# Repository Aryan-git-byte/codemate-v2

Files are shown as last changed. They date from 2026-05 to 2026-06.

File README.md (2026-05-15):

# Overview:
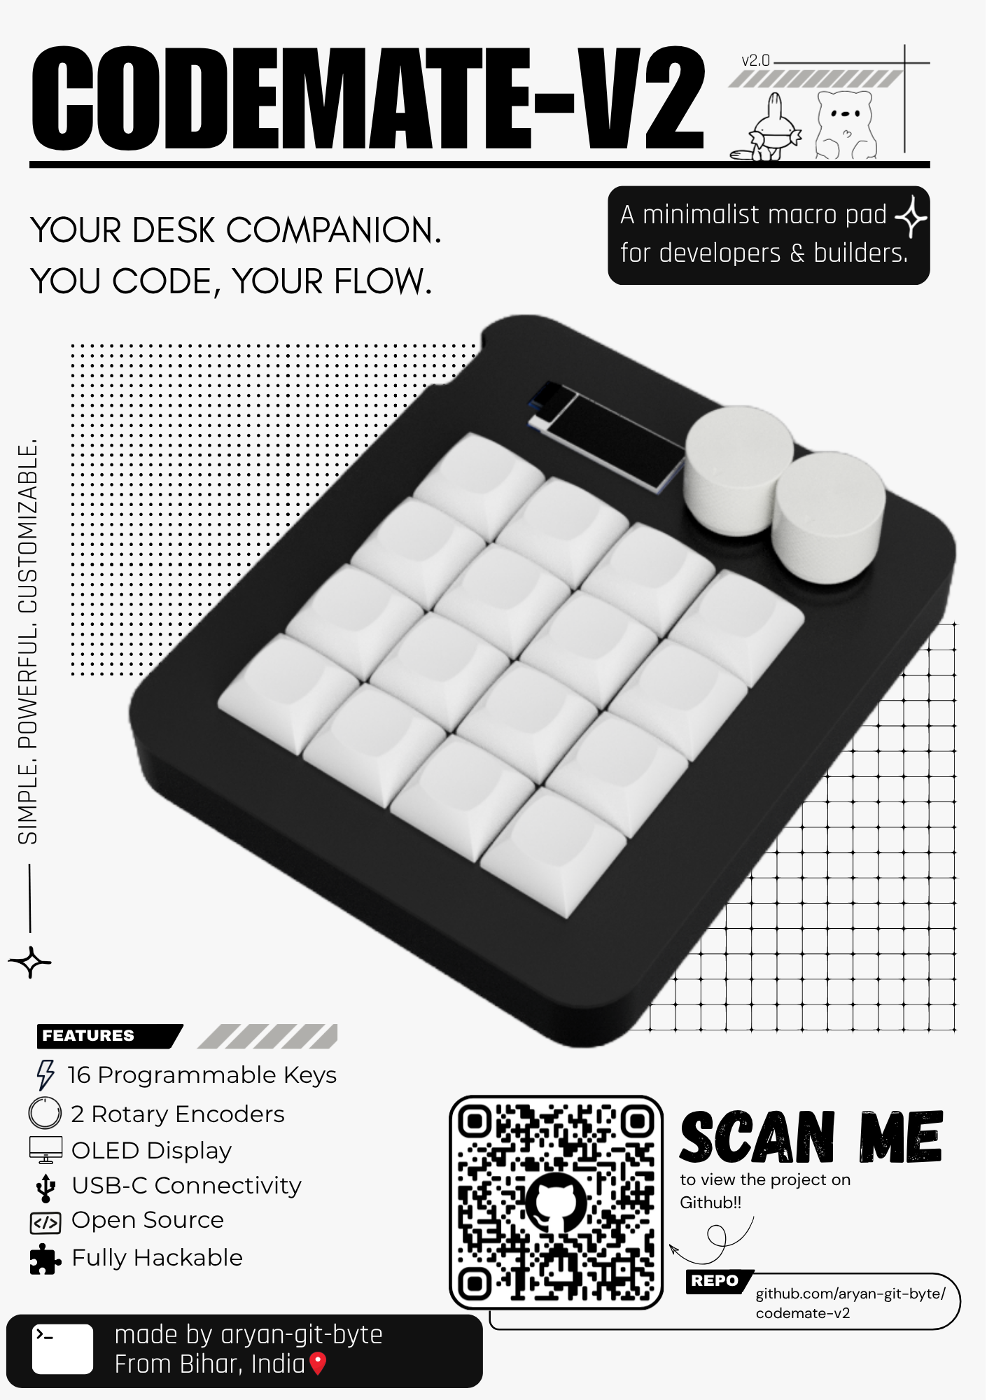
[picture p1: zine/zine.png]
zine

# What is this??
Yo, this is a 4x4 custom macropad that you can use for making ur life ezz, lol
it has 16 macros, 2 rotary encoders, RGB lights and an OLED display. and also it is a successor of my previous macropad [Codemate](https://github.com/aryan-git-byte/codemate).
# Use case:
whether you are a programmer, 3d modeller, editor or whatever u can easily use this macropad with just a little bit tweak in its firmware.
# Schematic Overview:
this is the schematic of the project, which u can see here:
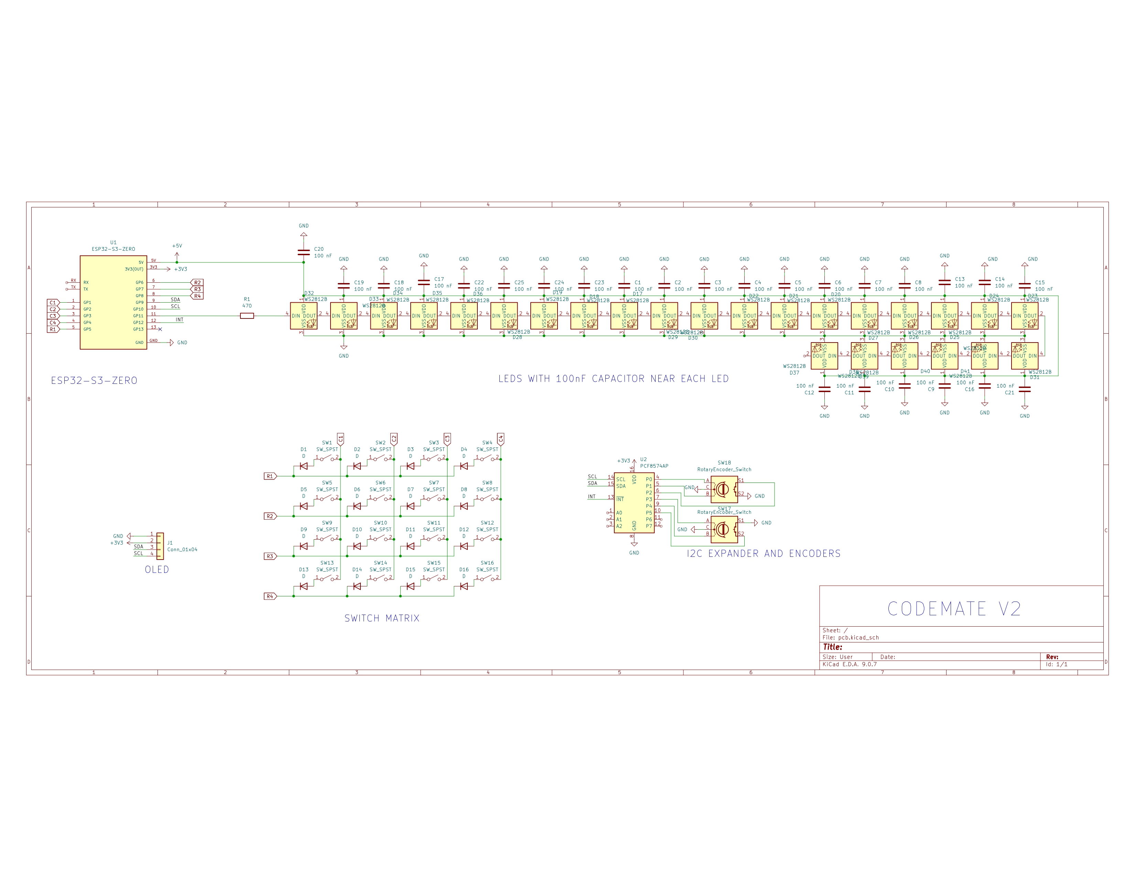
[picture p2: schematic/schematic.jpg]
schematic

you can see the MCU, the key matrix, the LEDs, encoders, everything in this schematic.
# why i made it??
cuz i believe that having a macropad can ezz my workflow and also give make it faster and more efficient.
# PCB overview:
for this i am using a 2 layer pcb board:
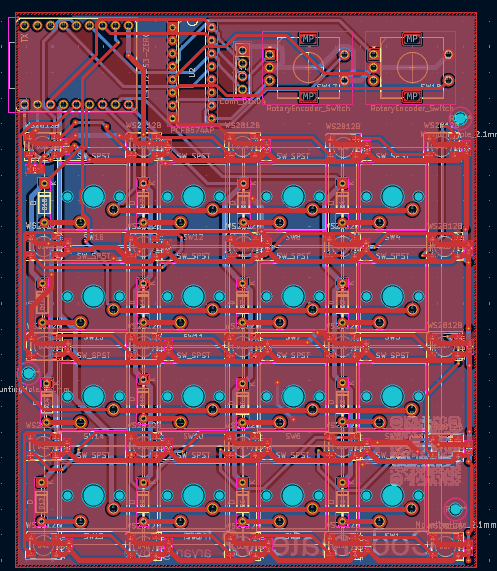
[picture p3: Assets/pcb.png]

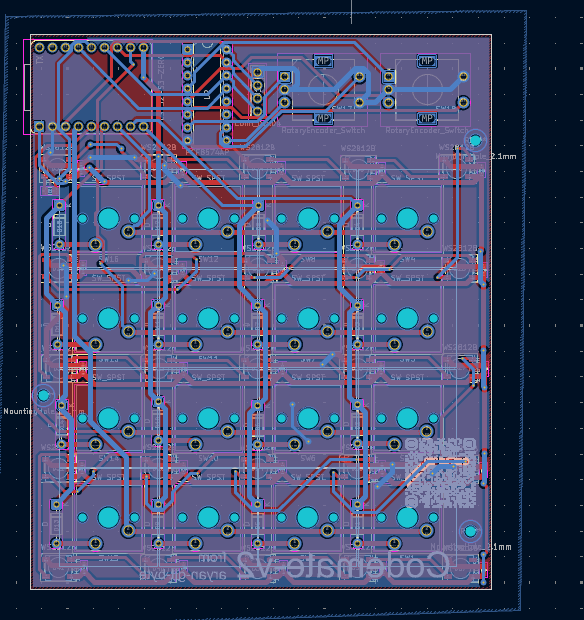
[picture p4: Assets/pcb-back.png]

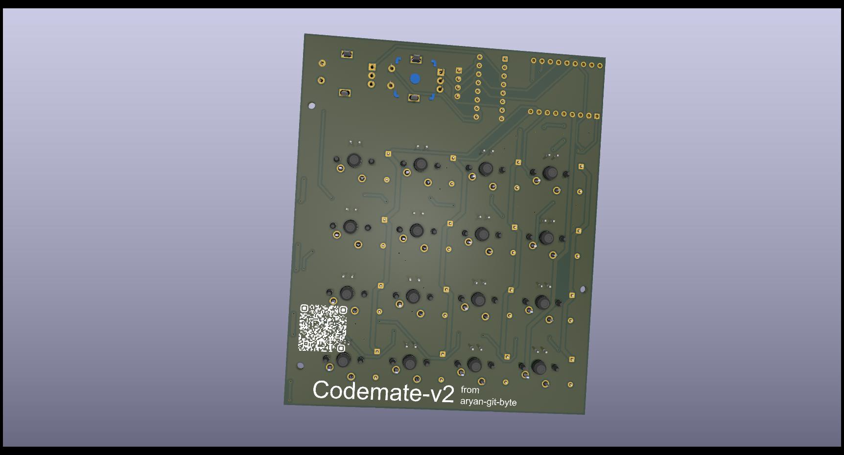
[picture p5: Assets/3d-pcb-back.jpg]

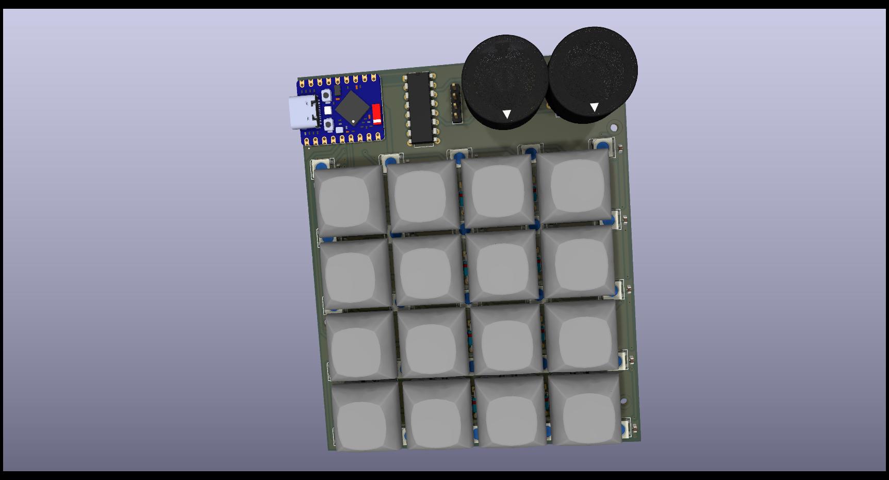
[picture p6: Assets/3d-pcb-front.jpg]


# How to Assemble
1. get the pcb ordered and solder all the components to it carefully
2. get these things 3d printed:
    1. [top-plate](3D-models/printable/TopPanel.stl) - 1x
    2. [main-body](3D-models/printable/Main-Body.stl) - 1x
    3. [keycaps](<3D-models/printable/DSA 1u.step>) - 16x
    4. [encoders](3D-models/printable/EncoderKnob.step) - 2x
3. cover it with the top plate
4. drill a 2 mm hole near the red holes:
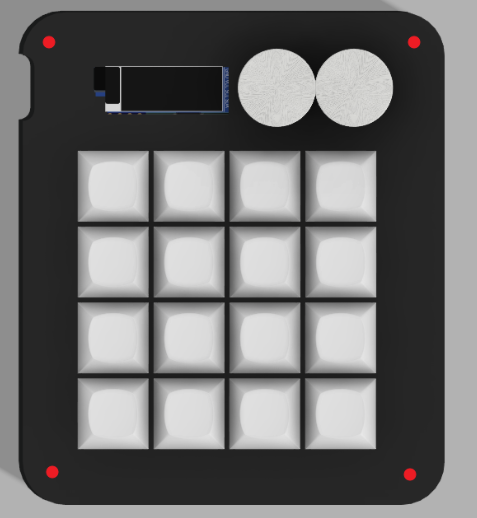
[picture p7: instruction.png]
instruction

5. insert 4 m3 inserts in these holes on the main body.
6. Now, put the soldered pcb with all the components inside the main-body
7. put the top panel , and put m3 screws. 
8. now put the keycaps and the knob onto it.
9. enjoy <3
# Firmware:
written in Arduino framework for ESP32-S3 Zero using these libraries:
- [FastLED](https://github.com/FastLED/FastLED) — RGB control
- [Keypad](https://github.com/Chris--A/Keypad) — key matrix
- [Adafruit SSD1306](https://github.com/adafruit/Adafruit_SSD1306) — OLED
- [Adafruit PCF8574](https://github.com/adafruit/Adafruit-PCF8574) — IO expander for encoders
- USB HID (built into ESP32 Arduino core) — keyboard + media keys

### flashing steps:
1. opem [Arduino IDE](https://www.arduino-cc/en/software)
2. add ESP32 board support — paste this in Board Manager URL:
   `https://raw.githubusercontent.com/espressif/arduino-esp32/gh-pages/package_esp32_index.json`
3. install the libraries above from Library Manager
4. select board: `ESP32S3 Dev Module`
5. plug in USB into the devboard
6. upload `firmware/firmware.ino` from this repo
7. done
# BOM:
|item name | quantity | unit price | link | total price
|-|-|-|-|-
Esp32-s3 zero development board|1| 620 rs | [link](https://hubtronics.in/esp32-s3-zero-m?srsltid=AfmBOoq3kT32v8UczG0TNtBfSk1mz6VMTDCRHNpQfM2GaU1SiqyRmEIawpQ)| 620 rs 
Blue MX cherry switches ( pack of 10)| 2 | 350 rs | [link](https://meckeys.com/shop/accessories/keyboard-accessories/key-switches/cherry-mx2a-switch/)| 700 rs
Oled 0.91"|1|198 rs |[link](https://hubtronics.in/0.91inch-4pin-oled-display-module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)|198 rs 
PCF8574AP | 1 | 124 rs | [link](https://robu.in/product/pcf8574an-texas-instruments-pcf8574an-i-o-expander-8-bit-i2c-2-5-v-6-v-dip-16-pins/)|128 rs
EC11 rotary encoder|2|64 rs | [link](https://www.flyrobo.in/15mm-ec11-rotary-encoder-with-switch-digital-potentiometer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) | 128 rs 
WS2812B | 40 | 4.72 rs | [link](https://hubtronics.in/ws2812b-5050-led?srsltid=AfmBOopNwODVwO3OMV0OqoXZXVZTHtyzRN5Mug-3Q1g00d0sAzbv55LT4r4)| 188.80 rs
470 ohm 0805 resistor (pack of 20)| 1| 8 rs | [link](https://quartzcomponents.com/products/470ohm-470e-5-smd-resistor-0805-pack-of-20-pieces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)|8 rs
100 nF Capacitor 0603 (pack of 20)|2|11 rs | [link](https://quartzcomponents.com/products/kemet-100nf-50v-0603-smd-pack-x7r-multilayer-ceramic-capacitor-10-tolerence-pack-of-20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)| 22 rs
 Diode (1N4148)|25|3 rs |[link](https://quartzcomponents.com/products/1n4148-zener-diode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)|75 rs
hubtroncs shipping charge| 1 | 75 rs | | 75 rs 
Meckkeys shipping charge | 1 | 100 rs | | 100 rs
FlyRobo shipping | 1 | 59 rs | | 59 rs 

[ Note: the components from the quartz component and robu are budled with my other order of different project, otherwise if u are ordering it for yourself , it will be 100 rs each ]

Total: 2301 rs , (24 usd)

## PCB will be :   
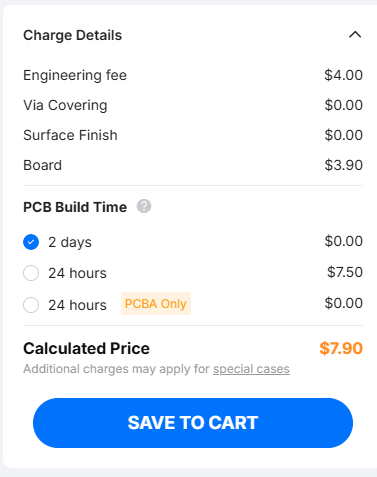
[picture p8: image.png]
jlcpcb
        

7 usd, shipping will be another 10 usd, but i m getting this shipped along with my different pcb.

# grand total : 31 usd

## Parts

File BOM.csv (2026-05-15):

item name | quantity | unit price | link | total price
Esp32-s3 zero development board | 1 | 620 rs | https://hubtronics.in/esp32-s3-zero-m | 620 rs
Blue MX cherry switches ( pack of 10) | 2 | 350 rs | https://meckeys.com/shop/accessories/keyboard-accessories/key-switches/cherry-mx2a-switch/ | 700 rs
Oled 0.91" | 1 | 198 rs | https://hubtronics.in/0.91inch-4pin-oled-display-module | 198 rs
PCF8574AP | 1 | 124 rs | https://robu.in/product/pcf8574an-texas-instruments-pcf8574an-i-o-expander-8-bit-i2c-2-5-v-6-v-dip-16-pins/ | 128 rs
EC11 rotary encoder | 2 | 64 rs | https://www.flyrobo.in/15mm-ec11-rotary-encoder-with-switch-digital-potentiometer?tracking=ads | 128 rs
WS2812B | 40 | 4.72 rs | https://hubtronics.in/ws2812b-5050-led | 188.80 rs
470 ohm 0805 resistor (pack of 20) | 1 | 8 rs | https://quartzcomponents.com/products/470ohm-470e-5-smd-resistor-0805-pack-of-20-pieces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 | 8 rs
100 nF Capacitor 0603 (pack of 20) | 2 | 11 rs | https://quartzcomponents.com/products/kemet-100nf-50v-0603-smd-pack-x7r-multilayer-ceramic-capacitor-10-tolerence-pack-of-20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 | 22 rs
Diode (1N4148) | 25 | 3 rs | https://quartzcomponents.com/products/1n4148-zener-diode?variant=42817413546218&country=IN&currency=INR | 75 rs
hubtroncs shipping charge | 1 | 75 rs |  | 75 rs
Meckkeys shipping charge | 1 | 100 rs |  | 100 rs
FlyRobo shipping | 1 | 59 rs |  | 59 rs
PCB | 1 | 7 usd |  | 7 usd
PCB shipping | 1 | 10 usd |  | 10 usd
grand total | 1 | 31 usd |  | 31 usd

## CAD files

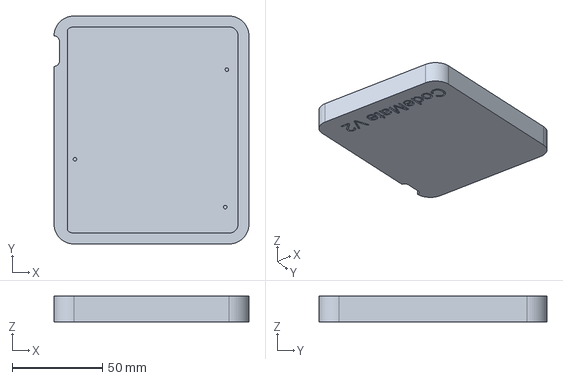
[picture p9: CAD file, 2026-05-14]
3D-models/printable/Main-Body.step
107.8 x 126.0 x 14.3 mm

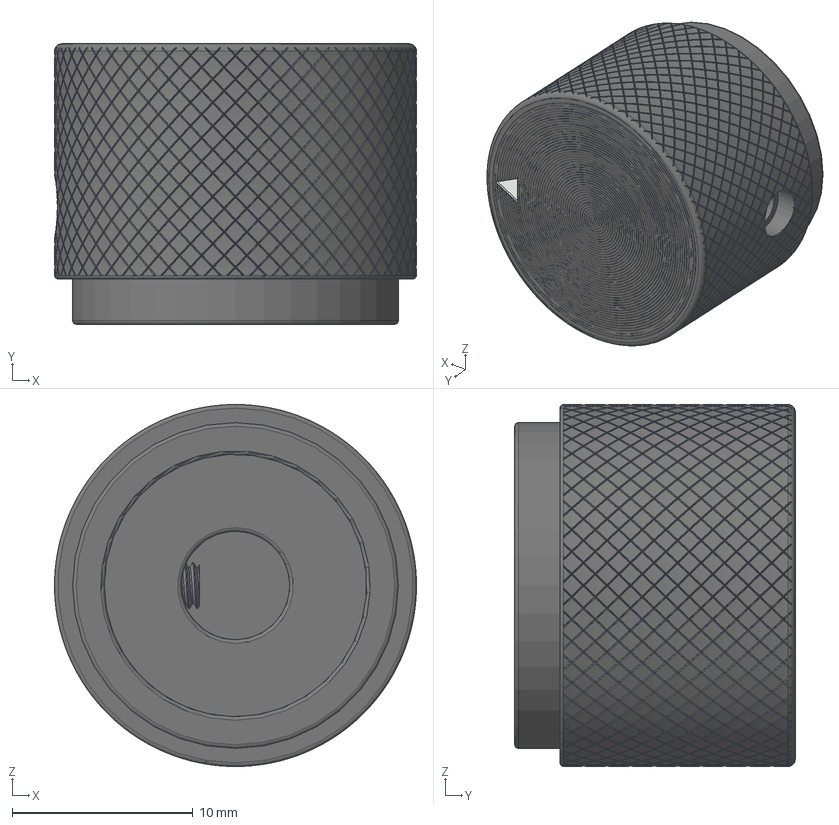
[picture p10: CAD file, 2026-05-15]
3D-models/printable/EncoderKnob.step
20.0 x 15.5 x 20.0 mm

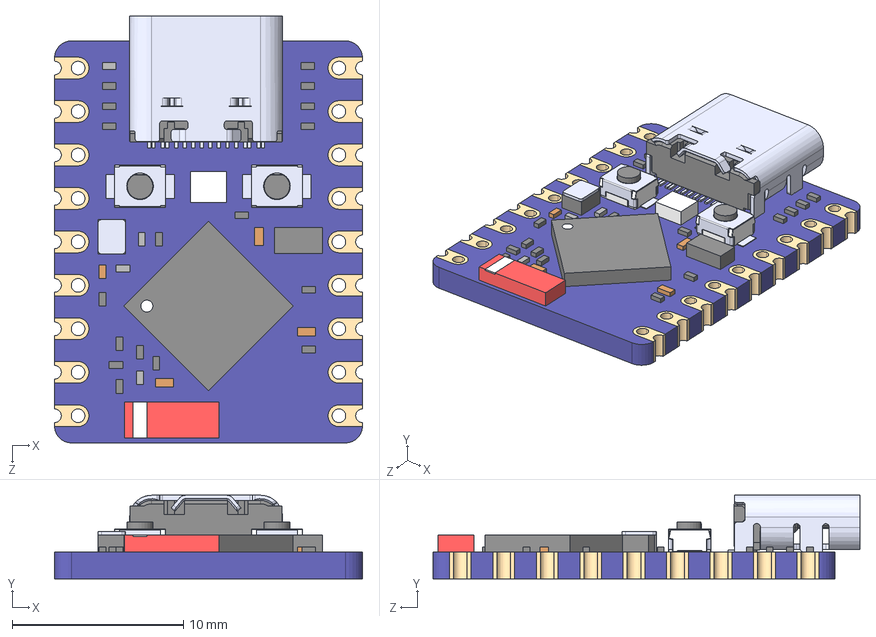
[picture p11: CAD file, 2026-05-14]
kicad/resources/ESP32-S3-ZERO.step
18.0 x 4.88 x 25.0 mm

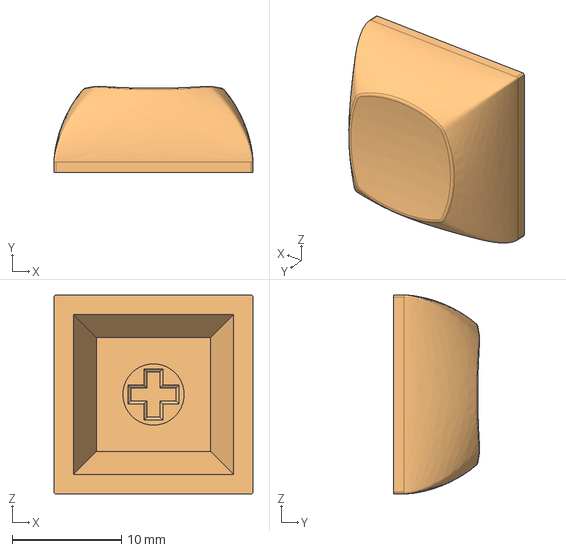
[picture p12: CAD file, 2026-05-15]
3D-models/printable/DSA 1u.step
18.2 x 7.91 x 18.2 mm

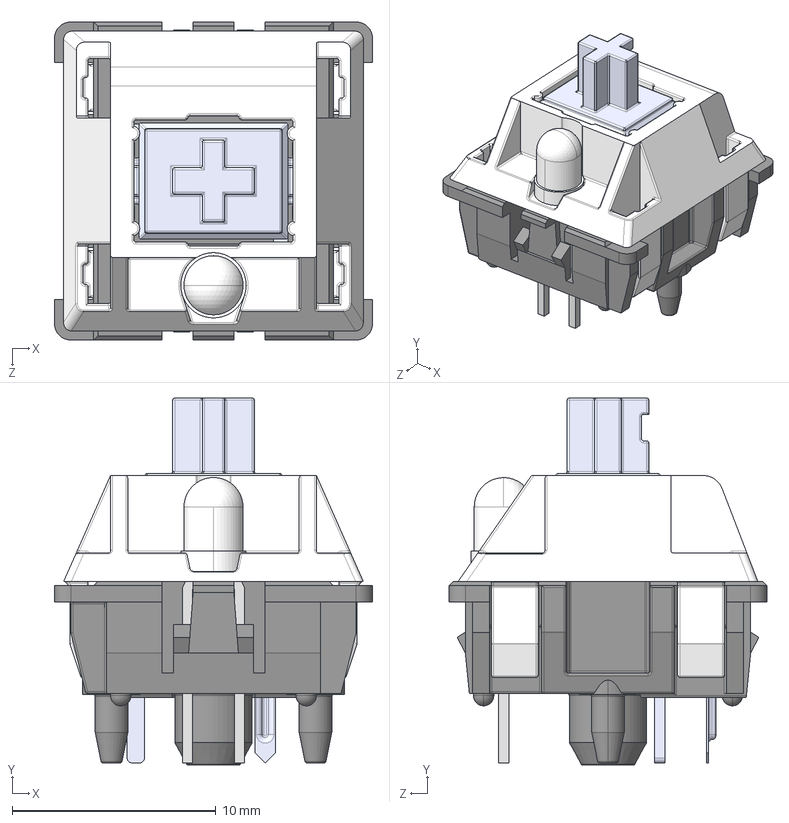
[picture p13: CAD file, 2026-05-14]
kicad/resources/Cherry MX.STEP
15.6 x 18.0 x 15.6 mm
Bottom
Pulsador
Top
Pieza5^Cherry MX
Pin1
Pin2
Led 3mm_trans

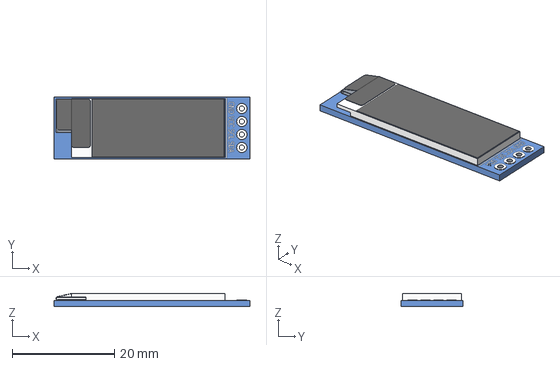
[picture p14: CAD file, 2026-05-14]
3D-models/printable/oled.step
38.3 x 12.1 x 2.57 mm

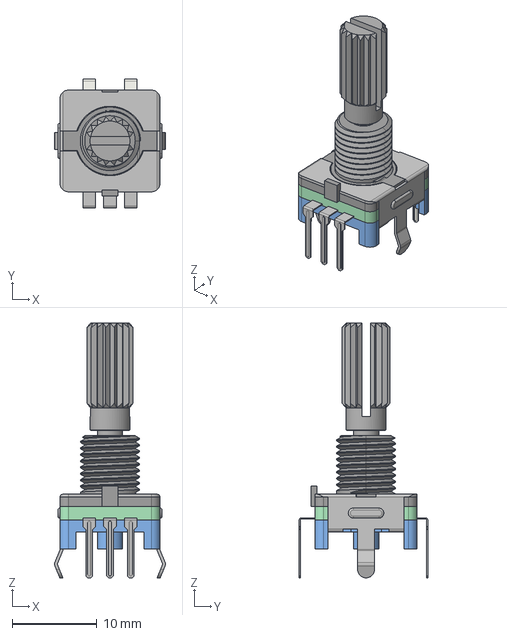
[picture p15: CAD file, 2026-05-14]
kicad/resources/EC11_Rotary_Encoder_Switched.step
13.1 x 15.3 x 30.1 mm

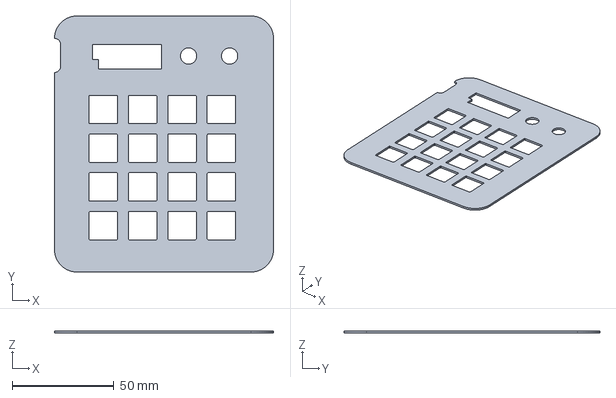
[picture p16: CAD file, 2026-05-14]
3D-models/printable/TopPanel.step
107.8 x 126.0 x 1.15 mm

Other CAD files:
3D-models/printable/Main-Body.stl
3D-models/printable/TopPanel.stl
3D-models/src/Main-Body.f3d
3D-models/src/TopPanel.f3d
3D-models/src/oled.f3d

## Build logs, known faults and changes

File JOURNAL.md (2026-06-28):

---
title: "Codemate-v2"
author: "Aryan-git-byte"
description: "A 16 key custom hackpad designed to ease simple tasks through one click , with rotary knob to control volumes etc , and a oled with cute eyes, tracking what u doing etc, and fully rgb board"
created_at: "2026-03-09"
---

# March 9th - 11th: Started schematic, assigned footprints, and routed PCB!

Hi so from the last few days i've been working on a project, but coudlnt journal it because i was using obs studio to record and it wasnt supported at that time, then i forgot.
so this is a combined journal of 3 days work, lets start:

**Date - 9/03**

so i wanted to upgrade my previous codemate (https://github.com/Aryan-git-byte/CodeMate)    
and make a version 2 of it, which will have more buttons & aesthetic too.   
so i outlined my need, and came to conclusion that i wanted a macropad which can help me in various tasks such as autodesk, or it can be used as calculator, and much more so i decided to use **16 SPSTs**, **2 Rotary encoder with Switch**, **1 OLED** and obviously **RGBs**. Also i wanted to use TFT at first , but that would be too big for my need, so i skipped it.

so with these requirements kept in mind i started searching for the components i wanted to use, first came the **MCU**,    
requirements? must've native usb, type c port, and enough pins.  

with this requirements i started searching for the perfect MCU, some MCU i looked upon were:    

> **Raspberry Pi pico W/2W** — these were great tbh but missed one thing they didnt had type c port, and microusb is a pain in ass tbh. so i skipped it    
> **xiao series** — they were uhh kinda expensive tbh here and also out of stock at most vendors    
> **esp32-s3-zero by waveshare** — chose this at last, satisfied all the requirements ✓

now next was oled & rotary with switch, they were easy to find.

now come the led , dude this was the hardest one to find,

| LED | Status |
|-----|---|
| neopixel | out of stock, no vendor in india |
| sk6812 | no vendor in india, and im not paying custom duties for these RGBs. |
| WS2812 | okay, okay these were good but i realized this late so i kept searching |

then i paused for a moment rethink my whole life, and then started drawing schematic, i first made the matrix, then i found out that i m lacking GPIOs so i added an **I2C expander** and pretty much completed the schematic with all the features, (which was later polished just a bit)

schematic on that date:

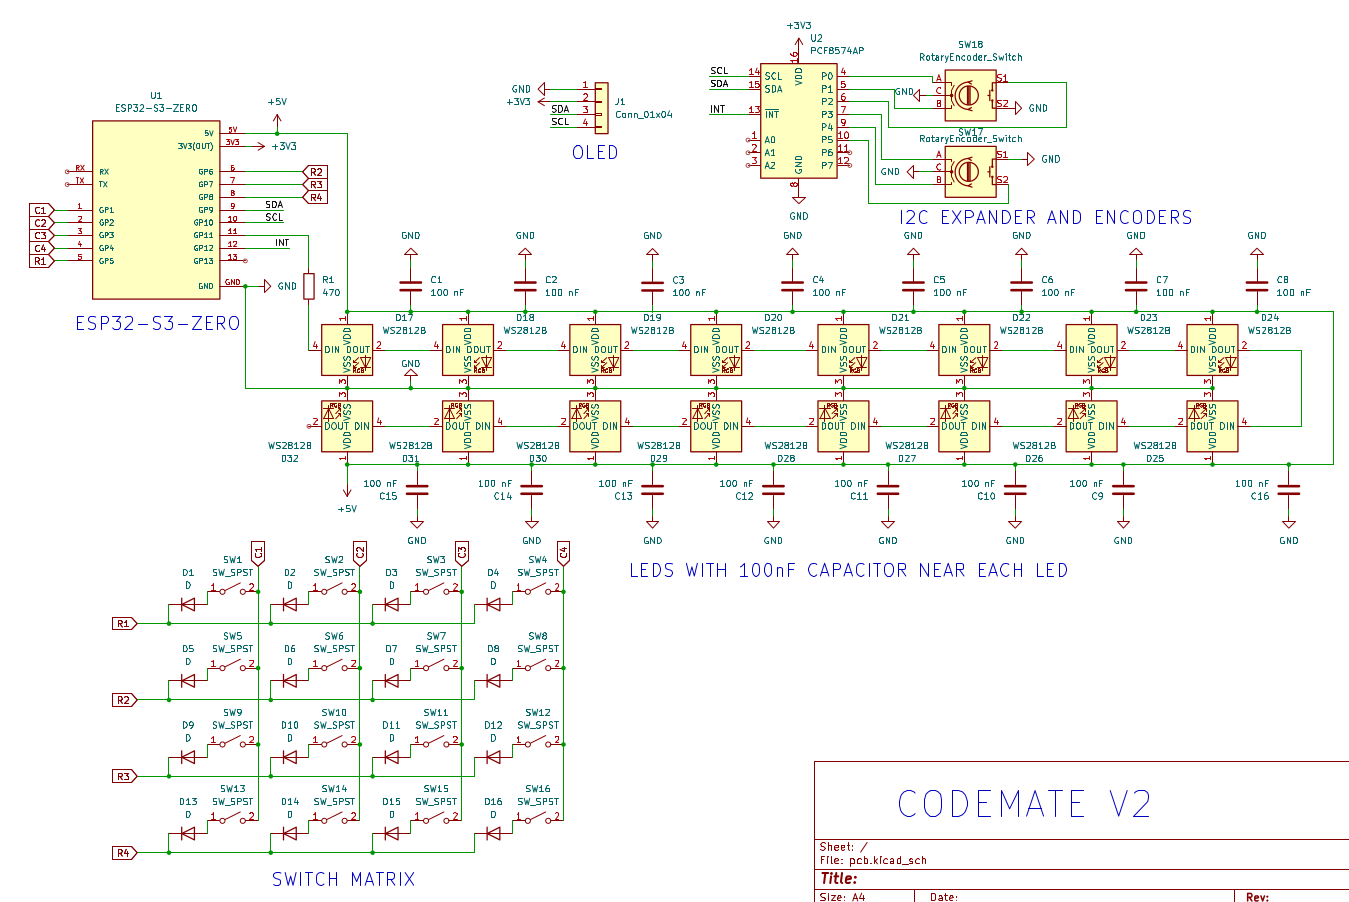
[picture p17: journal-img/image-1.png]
schematic


so yhh these were the work i did on 9 march

**10/03**

today i didnt did much work honestly, i just came and assigned all **footprints** and **3d models** of each symbol (yhh this was a pain too) i mean it didnt take that long but frustrated me enough 

today's work photo:

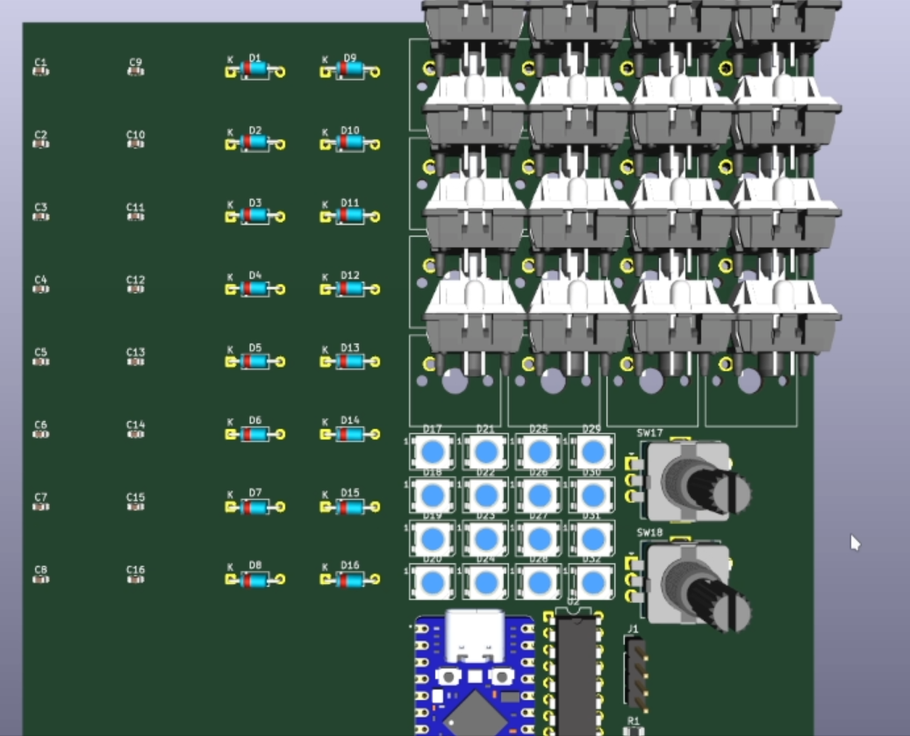
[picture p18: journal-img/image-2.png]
footprints


nnow dont ask me why are those switches that way in the photo (i fixed that thing when i wasnt recording afterwards, cuz it was a small change)

**11/03**

today i started my another peaceful day not knowing what is waiting for me in that scary software of **kicad**, i started recording opened kicad, everything seems to be going normal, i was routing then after some routing i came to routing leds, which were nightmare, all leds were placed not in numberwise but here & there so because of that i had to redo the schematic of the leds, arrange them in the way i had did in my pcb, so after all these i finally routed all the compennts and completed it.

the pcb , next is **3D model of the case**, which i believe willl be done soon

Youtube: https://youtu.be/ggxAWWdpk_k?si=SCKBwQzEbwkj9NhI

**Total time spent: ~5h 53 min**

# March 19th: Started CAD model of the case!

Today i started working on the CAD model of the codemate-v2, here are some pics:

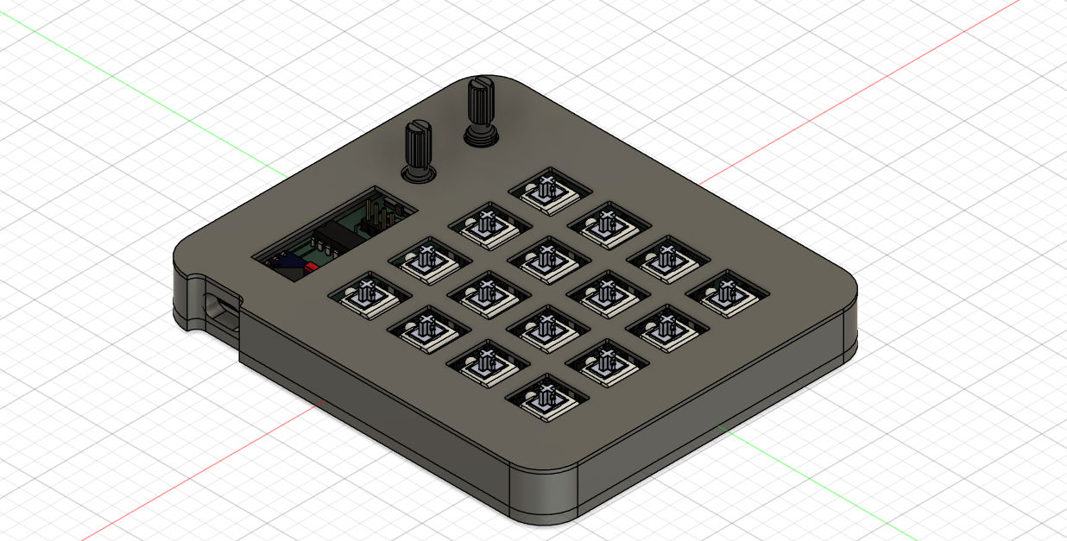
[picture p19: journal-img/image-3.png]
cad start


today i also changed my setup from that potato laptop to a beast pc (which is ofc my institute lab's pc) TT.

so i found out that my 3d models of some were missing so i assigned them again , then exported 3d model of the pcb , then made the case around it, starting with the **base**, then **walls**, then the **curvature for the type C**:

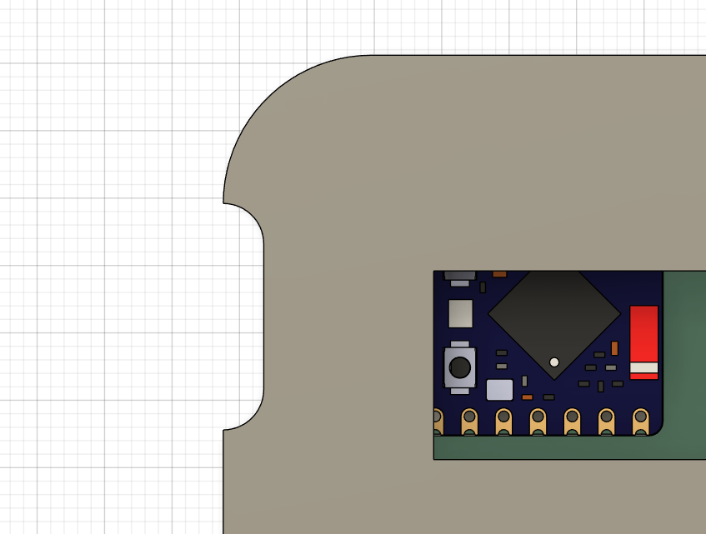
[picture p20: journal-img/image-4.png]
cad base


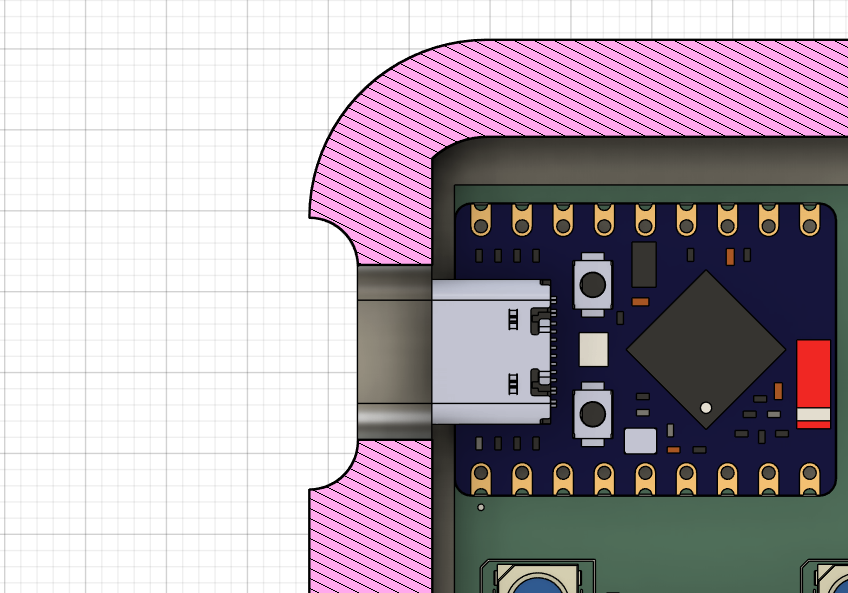
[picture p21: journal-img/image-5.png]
cad walls


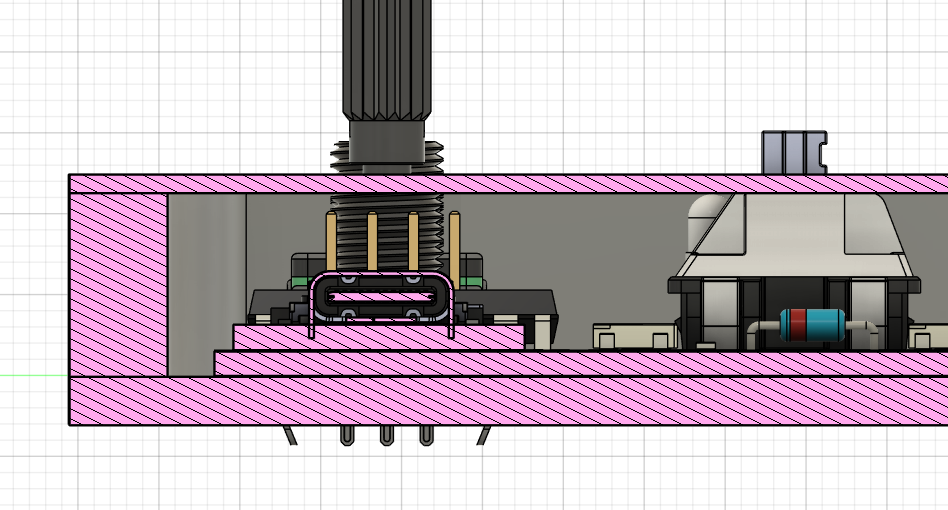
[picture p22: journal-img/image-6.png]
cad usbc curve


after which i imported my dxf from **ai03 plate generator**, and started making the top part.
and as of now i've completed this much design, will do polishing tmrw.

Lapse: https://public.lapse-hackclub.link/timelapses/jxMuQGCbdSnj/timelapse-jxMuQGCbdSnj.mp4

**Total time spent: ~2h 43 min**

---

# April 2nd: Finalizing files, organizing GitHub, and polishing CAD!

So i started working on the project and the goal of this session was to start finalizing my files so i can submit it and also start organizing the github, i started by working on the 3d model in which i had to do some works such as many bodies that were supposed to be combined were not, and when i tried it didnt let me combine em, i couldnt make new components etc. then i got to know about the **hybrid thing** , apparently my project was just a component or a body ig instead of hybrid design which allows us to put both bodies and components so i did that. combined bodies that were supposed to be together, and yes i also imported an oled 3d model and assembled it in the final assembly build in the CAD and did a bit branding on the backside because the front was already very populated. after which i read the docs and made sure my project is following everything. Polished the final assembly a bit then exported the **main body** & **front panel** separately and tried to render the full assembly from blender ,but i didnt know a shit on how that worked so i just ignored it.. after that i opened canva thinking to make the poster but i remebered about the firmware, so i went to read it docs, and figured out its kinda complicated but i'll figure it out.

the final build photo:

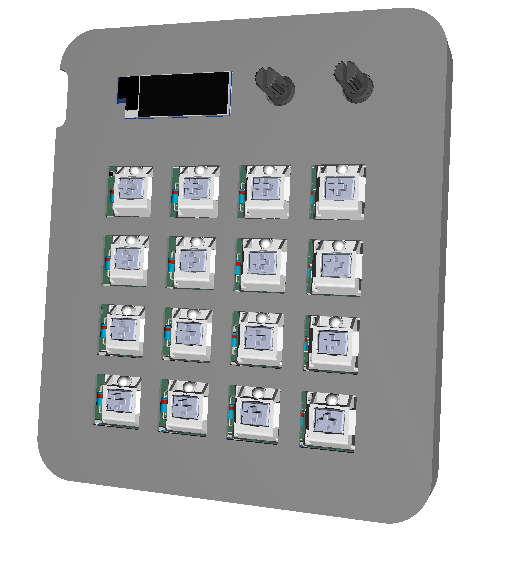
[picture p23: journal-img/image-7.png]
final build 1


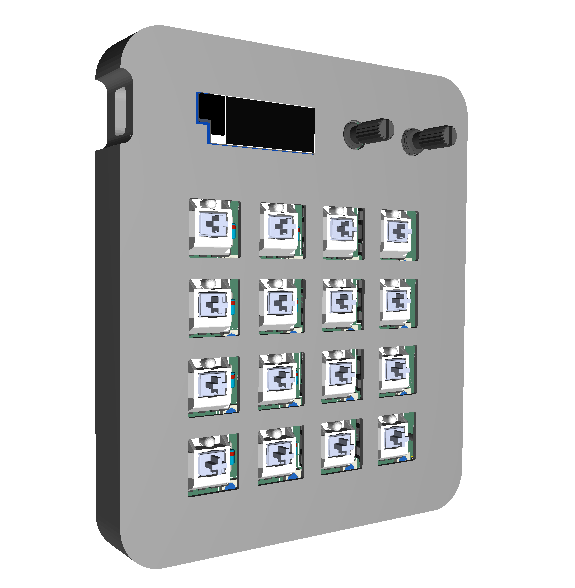
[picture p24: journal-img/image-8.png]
final build 2


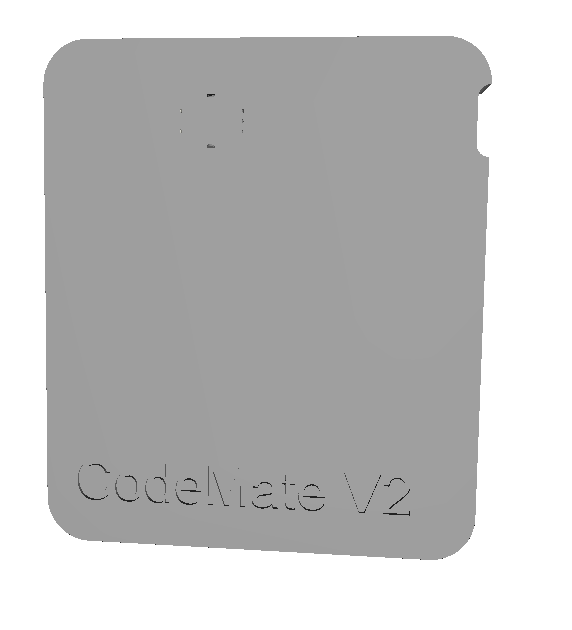
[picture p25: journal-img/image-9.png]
final build 3


Lapse: https://public.lapse-hackclub.link/timelapses/eKwN3tI9GYHY/timelapse-eKwN3tI9GYHY.mp4

**Total time spent: ~1h 35 min**

---

# April 3rd: Tested WS2812B NeoPixel LED code in Wokwi!

Today i read about the **WS2812B NeoPixel** led code, and tested it in **wokwi**.
first off which i started by setting up the file and wackatime to my **arduino ide**, after that i opened tinker cad and started tinkering with the WS2812B led and arduino to learn about how its code is written. then i downloaded the libraries and boards to my arduino ide and also synced all the timelapses to my hackatime project. then to test the WS2812B led with esp32 i opened the wokwi editor and read docs about the ws2812b led:

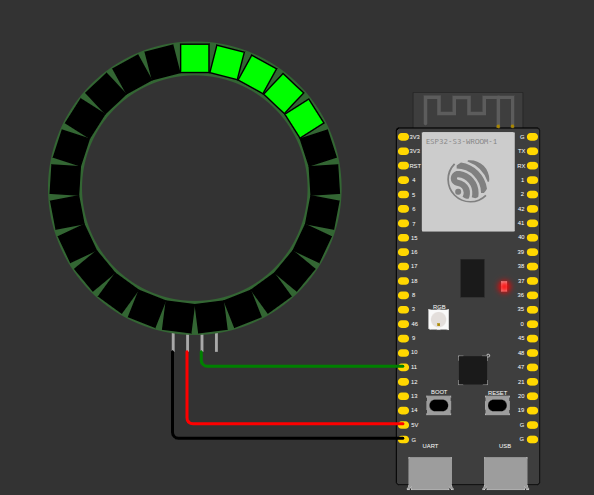
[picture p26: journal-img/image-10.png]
wokwi test


and then referencing my code from a doc from https://iotwebplanet.com/esp32-with-ws2812-neopixel-led/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
i got the code to test the leds on the board after soldering them and before soldering other components

Lapse: https://public.lapse-hackclub.link/timelapses/BJizs8soNoUa/timelapse-BJizs8soNoUa.mp4
Lapse: https://public.lapse-hackclub.link/timelapses/P3uvmIZazKJ7/timelapse-P3uvmIZazKJ7.mp4

**Total time spent: ~55 min**

---

# April 19th: Fought Blender (and lost... for now)

yoo, why blender is so hardd mannn, like this time again i tried to use blender but god damn itt.
i had to install like **3 versions** of it , then i got the plugin **pcb2blender** working. and even after importing it i didnt knew what to do with this mann 

blender struggle

Lapse: https://public.lapse-hackclub.link/timelapses/H7cz5NOCKMke/timelapse-H7cz5NOCKMke.mp4

**Total time spent: ~16 min**

---

# April 22nd: Assigned keycap and knob 3D models, imported to Fusion 360!

Hii, so today i started by opening the codemate-v2 PCB, and assigning **3d models of keycaps & knob** to switches and encoders, it was a hard time finding models as most were in **stl files**, but stilll i smhow converted those stls to steps and assigned em, and it looks pretyy nice now:

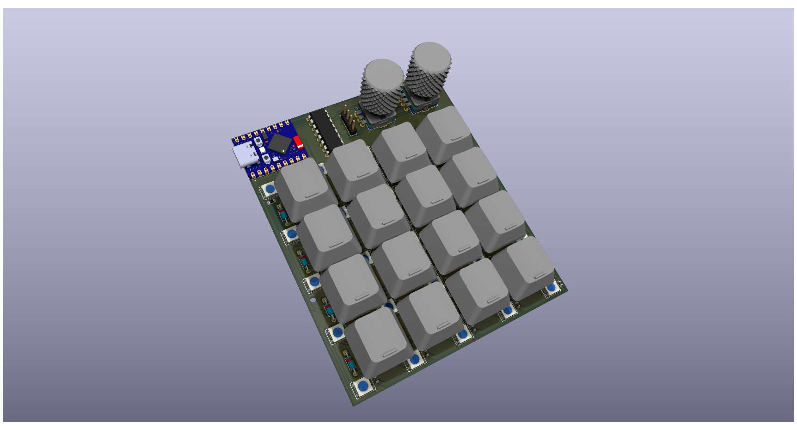
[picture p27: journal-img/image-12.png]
keycaps assigned


so after that i started to import this pcb in **fusion 360** and now will work on it further    

Lapse: https://public.lapse-hackclub.link/timelapses/jFNNw9AM3DWv/timelapse-jFNNw9AM3DWv.mp4

**Total time spent: ~1h 4 min**

---

# May 2nd: Rendered PCB in Fusion 360 and fixed GPU strain issues!

i started by importing the exported 3d model of my pcb in kicad but omg the strain it was putting on my gpu and cpu due to its **millions of faces** but still i thought this is workable and i tried to work with this:

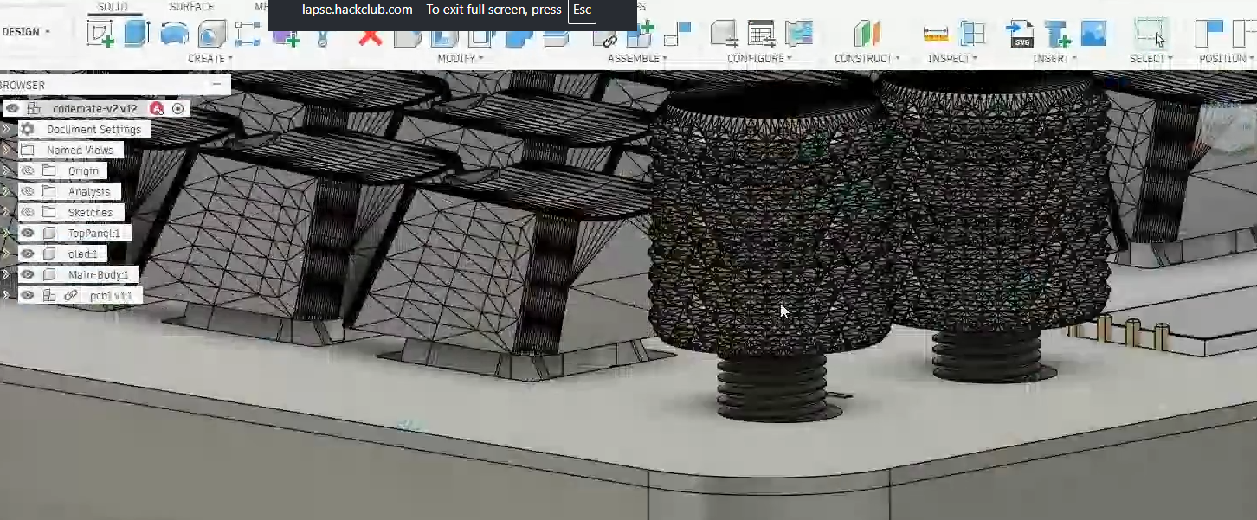
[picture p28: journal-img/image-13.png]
fusion heavy


and rendered it :

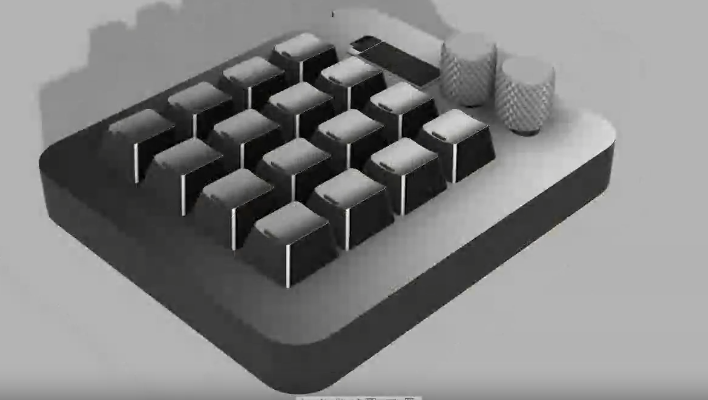
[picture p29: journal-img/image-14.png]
render


so after that i came back 2 days later , trying to render it beautifully again and adding appearances to faces etc
but this was so heavy heavy that i had to work on fixing it.
i searched for ways, asked people in the slack and they told me to **change the model of the keycap and the knob** so i did it . After that it was workign as smooth as butter so i continued forward

Lapse: https://public.lapse-hackclub.link/timelapses/GyKJ0a0nzVtK/timelapse-GyKJ0a0nzVtK.mp4
Lapse: https://public.lapse-hackclub.link/timelapses/nAhz6AsD8Oq7/timelapse-nAhz6AsD8Oq7.mp4

**Total time spent: ~1h 29 min**

---

# May 14th: Final render done and zine designed!

I started by first opening fusion 360 and rendering my product which turned out very good: 

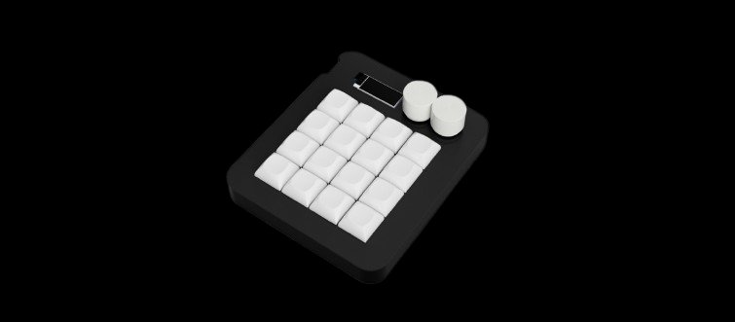
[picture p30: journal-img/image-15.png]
final render


After that I started working on the **zine** which also turned out very good :

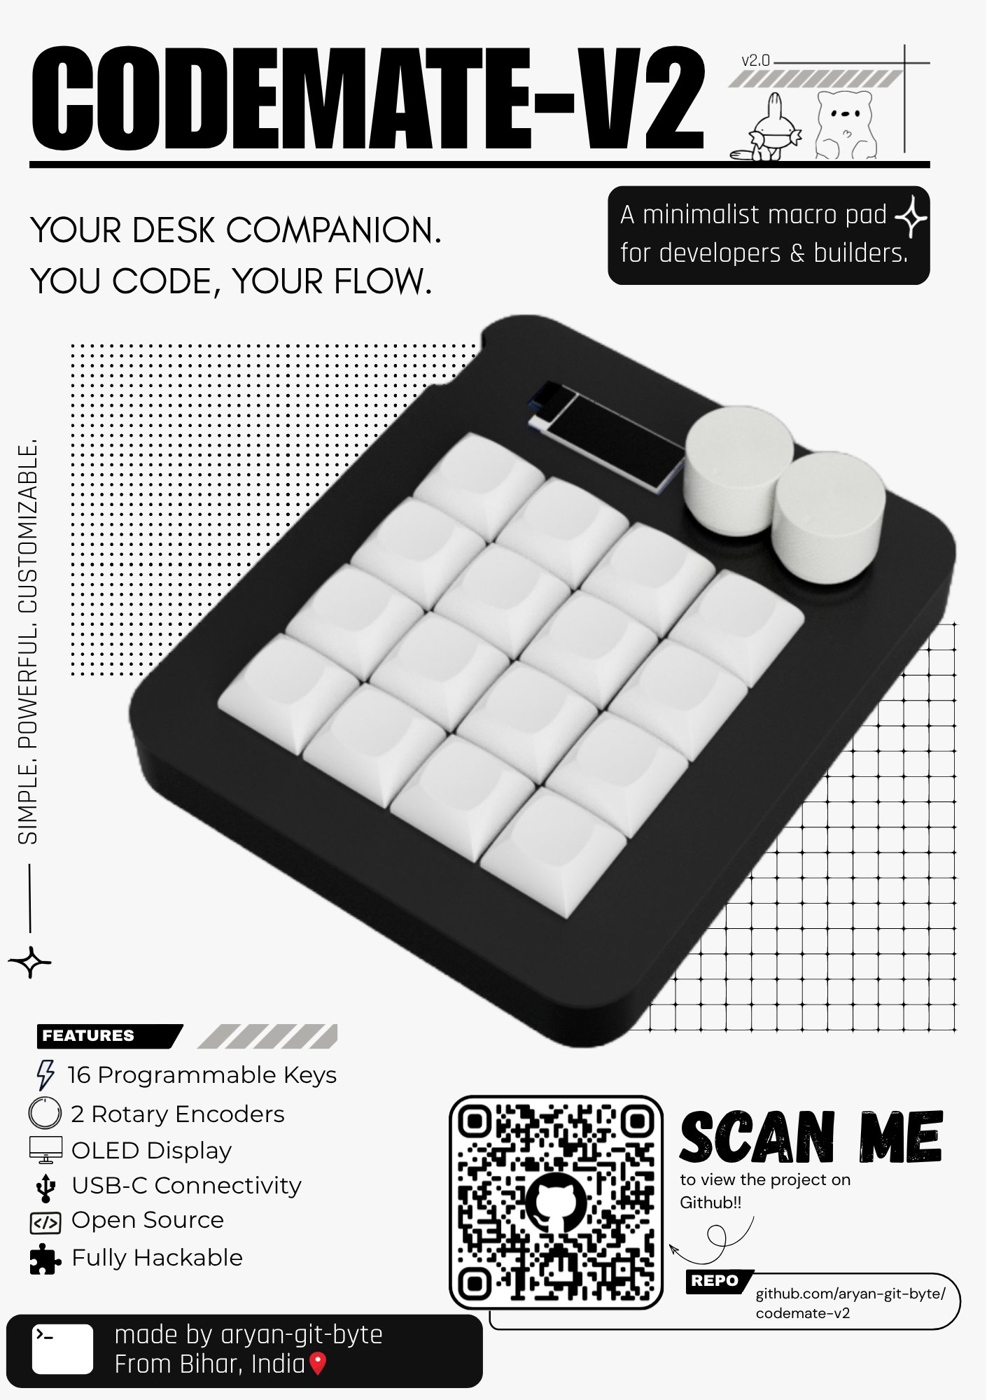
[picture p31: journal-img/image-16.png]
zine


Its a very minimalist aesthetic zine, my favourite as of now

So after both of these i arranged my repo and also started searching for the **BOM** 

Lapse: https://public.lapse-hackclub.link/timelapses/e-RqM5W6dsiw/timelapse-e-RqM5W6dsiw.mp4

**Total time spent: ~3h 1 min**

---

# May 15th: Completed BOM and finalized repo!

i started by completing my **BOM**:

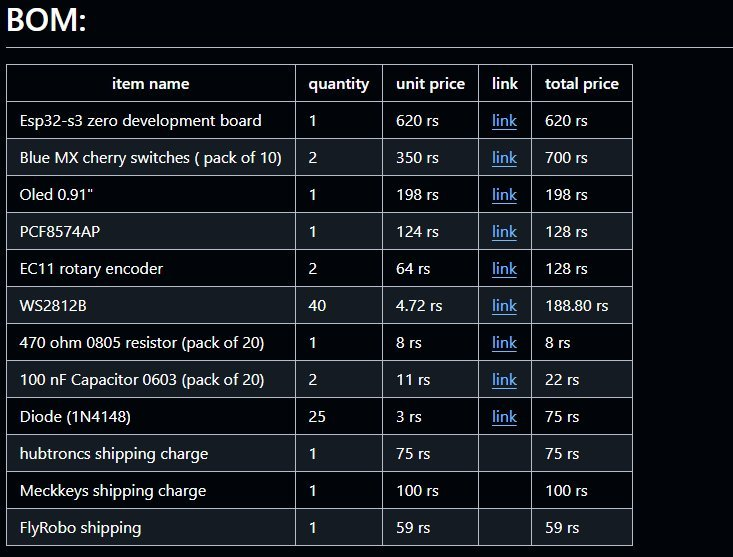
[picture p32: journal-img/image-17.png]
bom


which u can see in my repo.
after that i also arranged my repo and added everything and also wrote the readme 

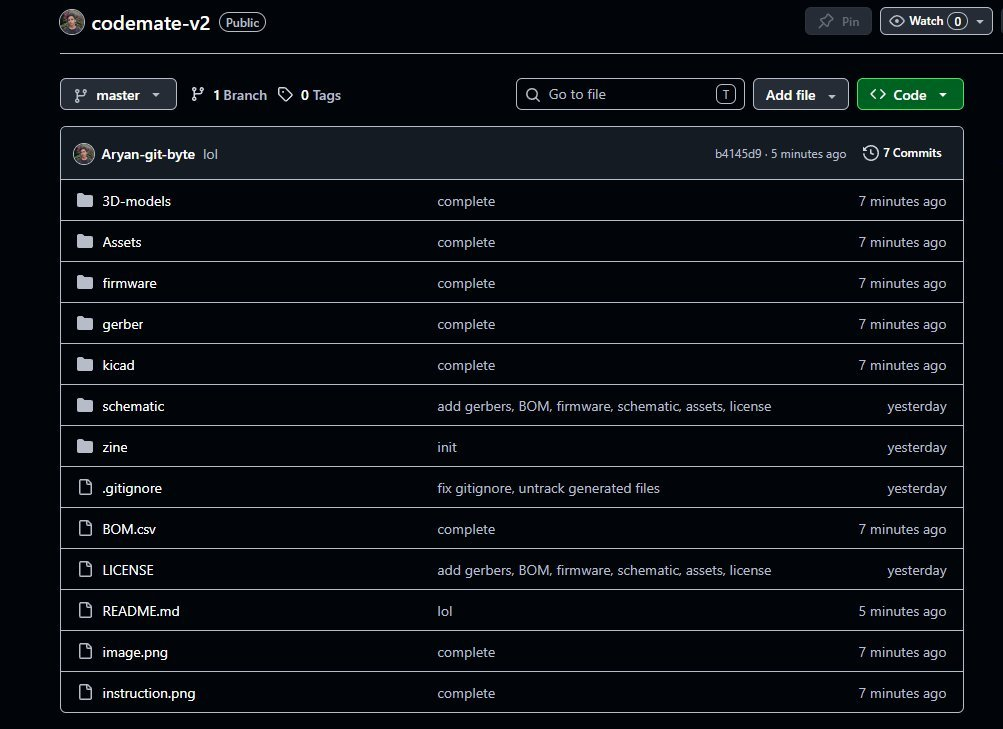
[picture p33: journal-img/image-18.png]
readme


Lapse: https://public.lapse-hackclub.link/timelapses/yTrNAkjzAvJ_/timelapse-yTrNAkjzAvJ_.mp4

**Total time spent: ~47 min**

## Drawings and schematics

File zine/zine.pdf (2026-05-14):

# CODEMATE-V2

YOUR DESK COMPANION.

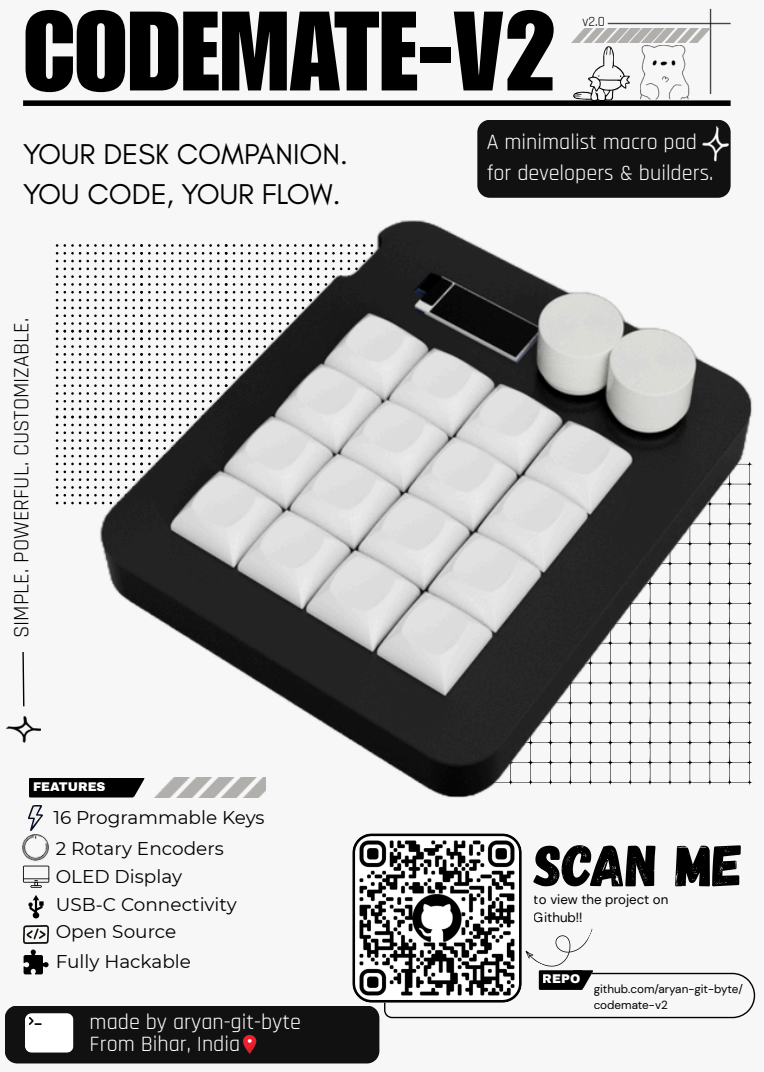
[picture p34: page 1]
REPO; FEATURES; SCAN ME; SIM; MIZ; 16 Programmable Keys 2 Rotary Encoders OLED Display USB-C Connectivity Open Source Fully Hackable

A minimalist macro pad
for developers & builders.

YOU CODE, YOUR FLOW.

to view the project on
Github!!

github.com/aryan-git-byte/
codemate-v2

made by aryan-git-byte
From Bihar, India

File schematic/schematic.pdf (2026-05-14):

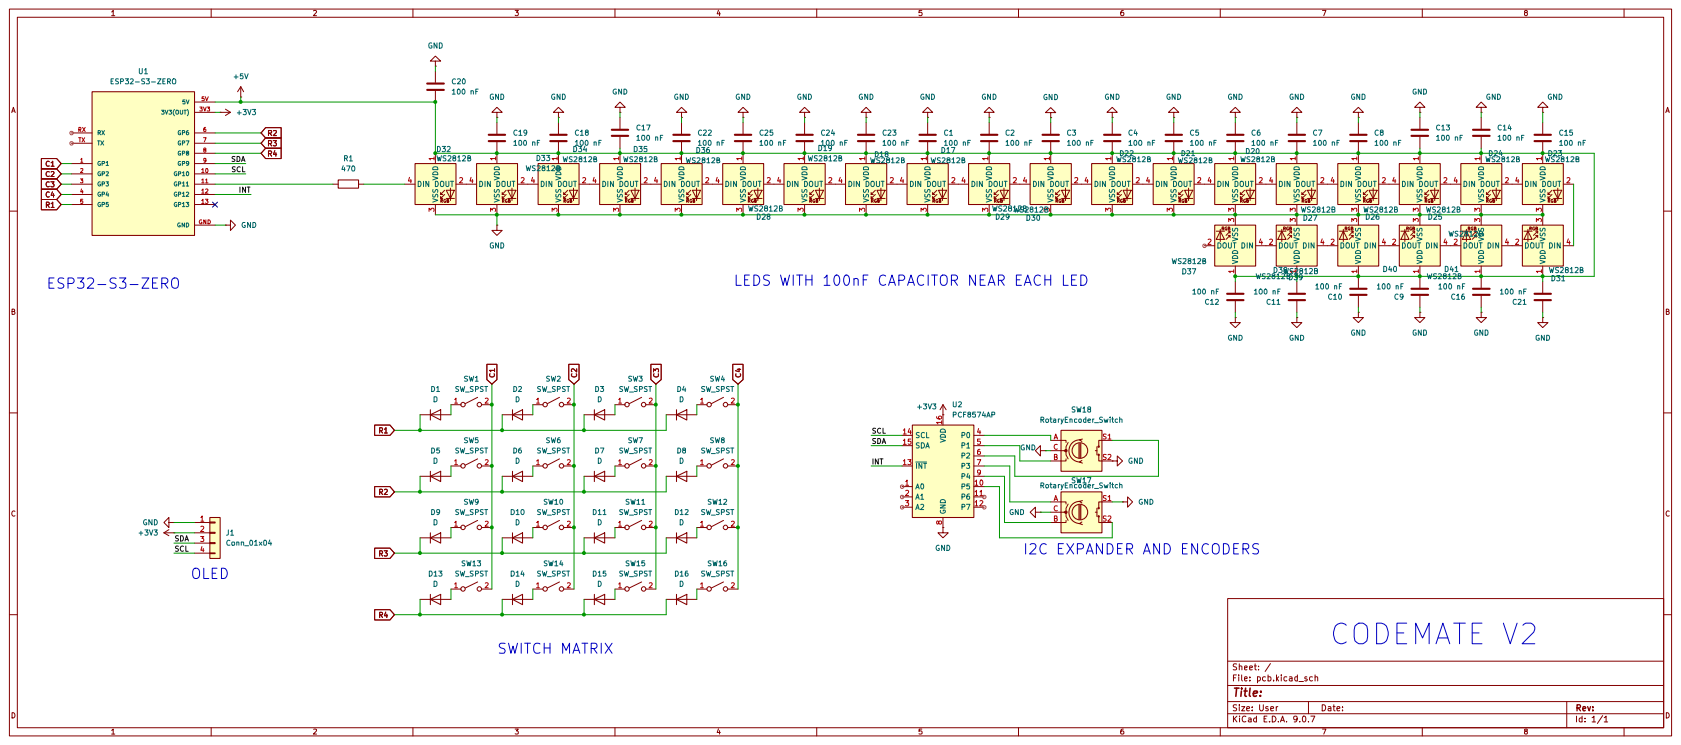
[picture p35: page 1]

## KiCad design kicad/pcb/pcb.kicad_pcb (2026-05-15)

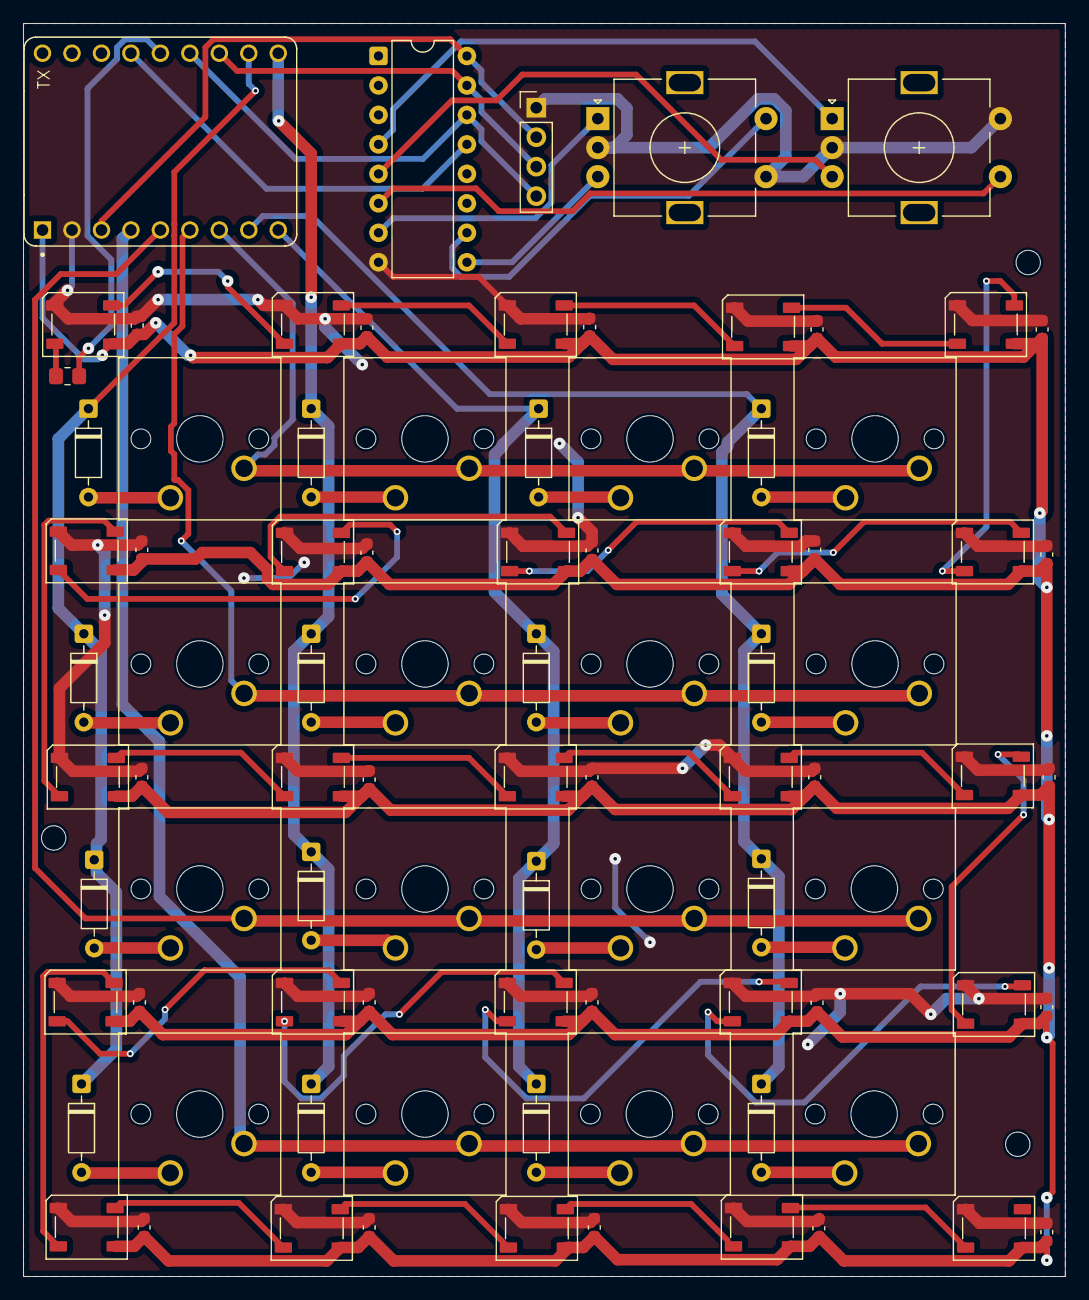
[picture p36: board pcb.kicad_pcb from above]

Board: 2 copper layers, 89.8 x 108.0 mm, 88 parts (0 on the bottom side), 62 nets.

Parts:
C1, C2, C3, C4, C5, C6, C7, C8, C9, C10, C11, C12, C13, C14, C15, C16, C17, C18, C19, C20, C21, C22, C23, C24, C25: 100 nF; C_0603_1608Metric
D1, D2, D3, D4, D5, D6, D7, D8, D9, D10, D11, D12, D13, D14, D15, D16: D; D_DO-35_SOD27_P7.62mm_Horizontal
D17, D18, D19, D20, D21, D22, D23, D24, D25, D26, D27, D28, D29, D30, D31, D32, D33, D34, D35, D36, D37, D38, D39, D40, D41: WS2812B; LED_WS2812B_PLCC4_5.0x5.0mm_P3.2mm
J1: Conn_01x04; PinHeader_1x04_P2.54mm_Vertical
R1: 470; R_0805_2012Metric_Pad1.20x1.40mm_HandSolder
SW1, SW2, SW3, SW4, SW5, SW6, SW7, SW8, SW9, SW10, SW11, SW12, SW13, SW14, SW15, SW16: SW_SPST; SW_Cherry_MX_1.00u_PCB
SW17, SW18: RotaryEncoder_Switch; RotaryEncoder_Alps_EC11E-Switch_Vertical_H20mm
U1: ESP32-S3-ZERO; MODULE_ESP32-S3-ZERO
U2: PCF8574AP; DIP-16_W7.62mm

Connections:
+3V3: J1.2, U1.3V3 (3V3(OUT)), U2.16 (VDD)
+5V: C1.2, C2.2, C3.2, C4.2, C5.2, C6.2, C7.2, C8.2, C9.2, C10.2, C11.2, C12.2, C13.2, C14.2, C15.2, C16.2, C17.2, C18.2, C19.2, C20.2, C21.2, C22.2, C23.2, C24.2, C25.2, D17.1 (VDD), D18.1 (VDD), D19.1 (VDD), D20.1 (VDD), D21.1 (VDD), D22.1 (VDD), D23.1 (VDD), D24.1 (VDD), D25.1 (VDD), D26.1 (VDD), D27.1 (VDD), D28.1 (VDD), D29.1 (VDD), D30.1 (VDD), D31.1 (VDD), D32.1 (VDD), D33.1 (VDD), D34.1 (VDD), D35.1 (VDD), D36.1 (VDD), D37.1 (VDD), D38.1 (VDD), D39.1 (VDD), D40.1 (VDD), D41.1 (VDD), U1.5V
/INT: U1.12 (GP12), U2.13 (~INT)
/SCL: J1.4, U1.10 (GP10), U2.14 (SCL)
/SDA: J1.3, U1.9 (GP9), U2.15 (SDA)
C1: SW1.2 (B), SW5.2 (B), SW9.2 (B), SW13.2 (B), U1.1 (GP1)
C2: SW2.2 (B), SW6.2 (B), SW10.2 (B), SW14.2 (B), U1.2 (GP2)
C3: SW3.2 (B), SW7.2 (B), SW11.2 (B), SW15.2 (B), U1.3 (GP3)
C4: SW4.2 (B), SW8.2 (B), SW12.2 (B), SW16.2 (B), U1.4 (GP4)
GND: C1.1, C2.1, C3.1, C4.1, C5.1, C6.1, C7.1, C8.1, C9.1, C10.1, C11.1, C12.1, C13.1, C14.1, C15.1, C16.1, C17.1, C18.1, C19.1, C20.1, C21.1, C22.1, C23.1, C24.1, C25.1, D17.3 (VSS), D18.3 (VSS), D19.3 (VSS), D20.3 (VSS), D21.3 (VSS), D22.3 (VSS), D23.3 (VSS), D24.3 (VSS), D25.3 (VSS), D26.3 (VSS), D27.3 (VSS), D28.3 (VSS), D29.3 (VSS), D30.3 (VSS), D31.3 (VSS), D32.3 (VSS), D33.3 (VSS), D34.3 (VSS), D35.3 (VSS), D36.3 (VSS), D37.3 (VSS), D38.3 (VSS), D39.3 (VSS), D40.3 (VSS), D41.3 (VSS), J1.1, SW17.C, SW17.S1, SW18.C, SW18.S2, U1.GND, U2.8 (GND)
unnamed: D1.2 (A), SW1.1 (A)
unnamed: D2.2 (A), SW2.1 (A)
unnamed: D3.2 (A), SW3.1 (A)
unnamed: D4.2 (A), SW4.1 (A)
unnamed: D5.2 (A), SW5.1 (A)
unnamed: D6.2 (A), SW6.1 (A)
unnamed: D7.2 (A), SW7.1 (A)
unnamed: D8.2 (A), SW8.1 (A)
unnamed: D9.2 (A), SW9.1 (A)
unnamed: D10.2 (A), SW10.1 (A)
unnamed: D11.2 (A), SW11.1 (A)
unnamed: D12.2 (A), SW12.1 (A)
unnamed: D13.2 (A), SW13.1 (A)
unnamed: D14.2 (A), SW14.1 (A)
unnamed: D15.2 (A), SW15.1 (A)
unnamed: D16.2 (A), SW16.1 (A)
unnamed: D17.4 (DIN), D18.2 (DOUT)
unnamed: D17.2 (DOUT), D29.4 (DIN)
unnamed: D18.4 (DIN), D19.2 (DOUT)
unnamed: D19.4 (DIN), D28.2 (DOUT)
unnamed: D20.4 (DIN), D21.2 (DOUT)
unnamed: D20.2 (DOUT), D27.4 (DIN)
unnamed: D21.4 (DIN), D22.2 (DOUT)
unnamed: D22.4 (DIN), D30.2 (DOUT)
unnamed: D23.4 (DIN), D24.2 (DOUT)
unnamed: D23.2 (DOUT), D31.4 (DIN)
unnamed: D24.4 (DIN), D25.2 (DOUT)
unnamed: D25.4 (DIN), D26.2 (DOUT)
unnamed: D26.4 (DIN), D27.2 (DOUT)
unnamed: D28.4 (DIN), D36.2 (DOUT)
unnamed: D29.2 (DOUT), D30.4 (DIN)
unnamed: D31.2 (DOUT), D41.4 (DIN)
unnamed: D32.4 (DIN), R1.2
unnamed: D32.2 (DOUT), D33.4 (DIN)
unnamed: D33.2 (DOUT), D34.4 (DIN)
unnamed: D34.2 (DOUT), D35.4 (DIN)
unnamed: D35.2 (DOUT), D36.4 (DIN)
unnamed: D37.4 (DIN), D38.2 (DOUT)
unnamed: D38.4 (DIN), D39.2 (DOUT)
unnamed: D39.4 (DIN), D40.2 (DOUT)
unnamed: D40.4 (DIN), D41.2 (DOUT)
unnamed: R1.1, U1.11 (GP11)
unnamed: SW18.A, U2.4 (P0)
unnamed: SW18.B, U2.5 (P1)
unnamed: SW18.S1, U2.6 (P2)
unnamed: SW17.A, U2.7 (P3)
unnamed: SW17.B, U2.9 (P4)
unnamed: SW17.S2, U2.10 (P5)
R1: D1.1 (K), D2.1 (K), D3.1 (K), D4.1 (K), U1.5 (GP5)
R2: D5.1 (K), D6.1 (K), D7.1 (K), D8.1 (K), U1.6 (GP6)
R3: D9.1 (K), D10.1 (K), D11.1 (K), D12.1 (K), U1.7 (GP7)
R4: D13.1 (K), D14.1 (K), D15.1 (K), D16.1 (K), U1.8 (GP8)

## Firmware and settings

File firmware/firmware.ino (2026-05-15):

#include <Wire.h>
#include <Keypad.h>
#include <FastLED.h>
#include <Adafruit_GFX.h>
#include <Adafruit_SSD1306.h>
#include <Adafruit_PCF8574.h>
#include "USB.h"
#include "USBHIDKeyboard.h"
#include "USBHIDConsumerControl.h"

// my pins
byte rPins[4] = {4, 5, 6, 7}; 
byte cPins[4] = {0, 1, 2, 3}; 

USBHIDKeyboard kb;
USBHIDConsumerControl media;
Adafruit_SSD1306 oled(128, 64, &Wire, -1);
Adafruit_PCF8574 pcf;
CRGB myLeds[16];

char myKeys[4][4] = {
  {'1', '2', '3', '4'}, 
  {'5', '6', '7', '8'}, 
  {'9', 'A', 'B', 'C'}, 
  {'D', 'E', 'F', 'G'}  
};
Keypad pad = Keypad(makeKeymap(myKeys), rPins, cPins, 4, 4);

uint8_t oldKnobs = 0xFF;
int vol = 50; 
bool quiet = false;

void setup() {
  Serial.begin(115200);
  
  kb.begin();
  media.begin();
  USB.begin();

  Wire.begin(); 
  oled.begin(SSD1306_SWITCHCAPVCC, 0x3C);
  oled.clearDisplay();
  sayThing("my macro", "yay!");

  pcf.begin(0x20, &Wire);
  pcf.digitalWriteByte(0xFF); // make inputs work
  
  FastLED.addLeds<WS2812B, 10, GRB>(myLeds, 16);
  FastLED.setBrightness(50);
}

void loop() {
  doLights();
  checkButtons();
  spinnyThings();
  delay(10); 
}

void doLights() {
  // math from internet
  float b = (exp(sin(millis() / 2000.0 * PI)) - 0.36787944) * 108.0;
  FastLED.setBrightness((uint8_t)b);
  for(int i = 0; i < 16; i++) {
    myLeds[i] = CRGB::Teal; // my fav color
  }
  FastLED.show();
}

void checkButtons() {
  char k = pad.getKey();
  if (k) {
    String msg = "";
    
    if(k == '1') { kb.press(KEY_LEFT_CTRL); kb.press('c'); delay(50); kb.releaseAll(); msg = "copy"; }
    if(k == '2') { kb.press(KEY_LEFT_CTRL); kb.press('x'); delay(50); kb.releaseAll(); msg = "cut"; }
    if(k == '3') { kb.press(KEY_LEFT_CTRL); kb.press('v'); delay(50); kb.releaseAll(); msg = "paste"; }
    if(k == '4') { kb.press(KEY_LEFT_GUI); kb.press(KEY_LEFT_SHIFT); kb.press('s'); delay(50); kb.releaseAll(); msg = "snip"; }
    
    if(k == '5') { kb.press(KEY_LEFT_CTRL); kb.press('z'); delay(50); kb.releaseAll(); msg = "undo"; }
    if(k == '6') { kb.press(KEY_LEFT_CTRL); kb.press('y'); delay(50); kb.releaseAll(); msg = "redo"; }
    if(k == '7') { kb.press(KEY_LEFT_CTRL); kb.press('s'); delay(50); kb.releaseAll(); msg = "save"; }
    if(k == '8') { kb.press(KEY_LEFT_CTRL); kb.press(KEY_LEFT_SHIFT); kb.press(KEY_ESC); delay(50); kb.releaseAll(); msg = "taskman"; }

    if(k == '9') { kb.write(KEY_F13); msg = "vscode"; }
    if(k == 'A') { kb.write(KEY_F14); msg = "cmd"; }
    if(k == 'B') { kb.write(KEY_F15); msg = "fusion"; }
    if(k == 'C') { kb.write(KEY_F16); msg = "chrome"; }

    if(k == 'D') { media.write(CONSUMER_CONTROL_PLAY_PAUSE); msg = "play"; }
    if(k == 'E') { media.write(CONSUMER_CONTROL_MUTE); msg = "shh"; }
    if(k == 'F') { kb.press(KEY_LEFT_GUI); kb.press('v'); delay(50); kb.releaseAll(); msg = "clip"; }
    if(k == 'G') { kb.press(KEY_LEFT_GUI); kb.press('l'); delay(50); kb.releaseAll(); msg = "bye"; }

    sayThing("button:", msg);
  }
}

void spinnyThings() {
  uint8_t now = pcf.digitalReadByte();
  
  if (now != oldKnobs) {
    
    // first knob vol
    uint8_t a1 = bitRead(now, 0);
    if (a1 != bitRead(oldKnobs, 0) && a1 == 1) { 
      if (bitRead(now, 1) != a1) {
        media.write(CONSUMER_CONTROL_VOLUME_UP);
        vol = min(100, vol + 2);
        sayThing("vol", String(vol) + "%");
      } else {
        media.write(CONSUMER_CONTROL_VOLUME_DOWN);
        vol = max(0, vol - 2);
        sayThing("vol", String(vol) + "%");
      }
    }

    // push to quiet
    if (bitRead(now, 2) == 0 && bitRead(oldKnobs, 2) == 1) {
      media.write(CONSUMER_CONTROL_MUTE);
      quiet = !quiet;
      if(quiet) sayThing("sound", "no");
      else sayThing("sound", "yes");
    }

    // second knob bright
    uint8_t a2 = bitRead(now, 4);
    if (a2 != bitRead(oldKnobs, 4) && a2 == 1) {
      if (bitRead(now, 5) != a2) {
        media.write(CONSUMER_CONTROL_BRIGHTNESS_UP);
        sayThing("sun", "up");
      } else {
        media.write(CONSUMER_CONTROL_BRIGHTNESS_DOWN);
        sayThing("sun", "down");
      }
    }

    // push for night
    if (bitRead(now, 6) == 0 && bitRead(oldKnobs, 6) == 1) {
      kb.write(KEY_F17); 
      sayThing("eyes", "safe");
    }

    oldKnobs = now;
  }
}

void sayThing(String line1, String line2) {
  oled.clearDisplay();
  oled.setTextSize(1);
  oled.setTextColor(SSD1306_WHITE);
  oled.setCursor(0,10);
  oled.println(line1);
  oled.setTextSize(2);
  oled.setCursor(0, 30);
  oled.println(line2);
  oled.display();
}
